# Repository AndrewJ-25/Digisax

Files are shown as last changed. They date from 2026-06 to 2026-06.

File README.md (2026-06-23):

# STARLITE

zine page

## Description
STARLITE is a minimalist Digital Saxophone (Digisax) controlled by ESP32-S3.

### Inspiration
This project is intended to be a cost effective, customisable alternative to commercially available wind synths. STARLITE can be used for both performance and silent practice. It weds my two favorite hobbies: music and tinkering.

### Features:
- realistic ergonomics
- UI in the form of an OLED display and rotary encoder, to control master volume and timbre
- differential pressure sensor for responsive breath control
- pressure tube and bleed tube to simulate realistic resistance to blowing
- audio synthesised locally
- 3x7 key matrix featuring MX Black switches
- power via 5V barrel jack
- DAC with headphone output

The neck can be blown into directly, but an alto saxophone mouthpiece is recommended. (Not included in this project.)

OnShape link: https://cad.onshape.com/documents/a64dba8dfd86a5efa1851173/w/8b62b2d00aa632cf961d9b4c/e/8ecfcb79b78c17c244b3f0aa

## Schematic and PCB

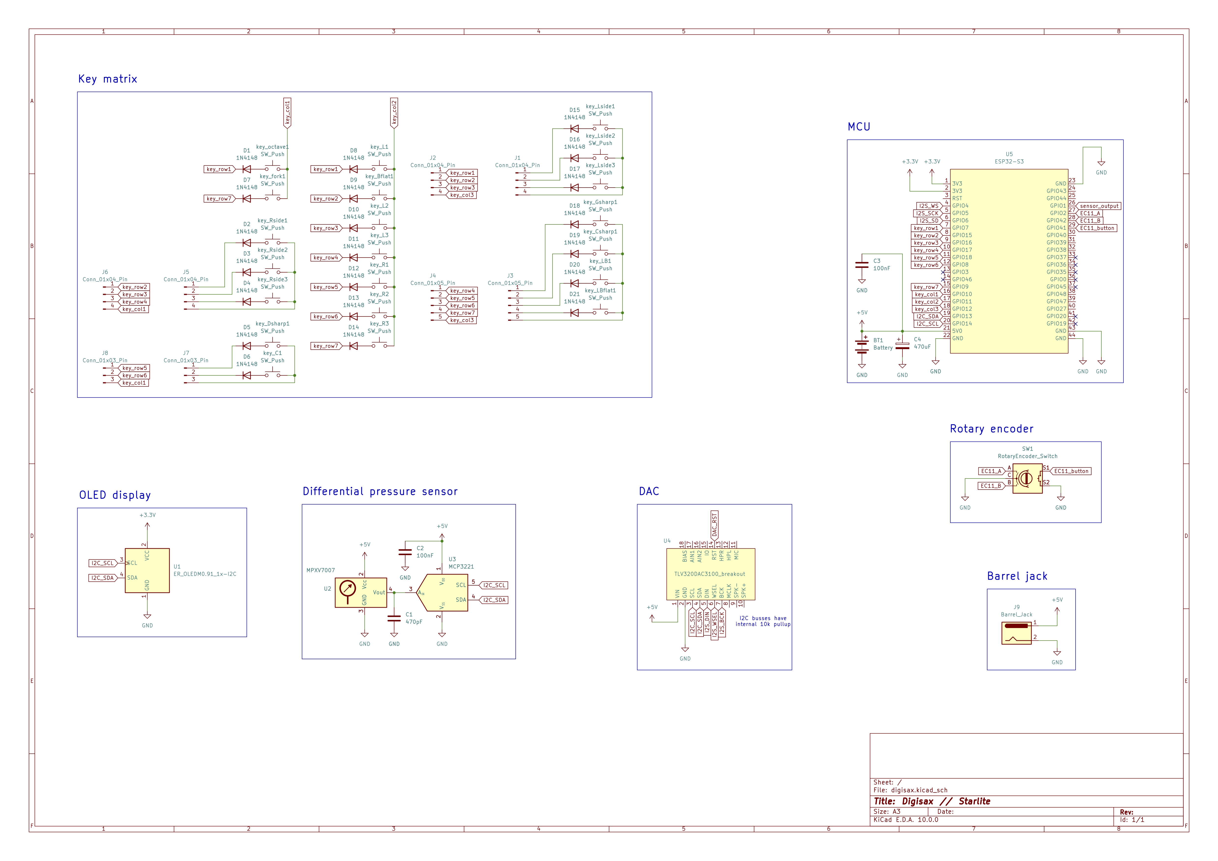
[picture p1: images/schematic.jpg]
Schematic view

A pdf version can be found under pcb/unconnected_pcb.

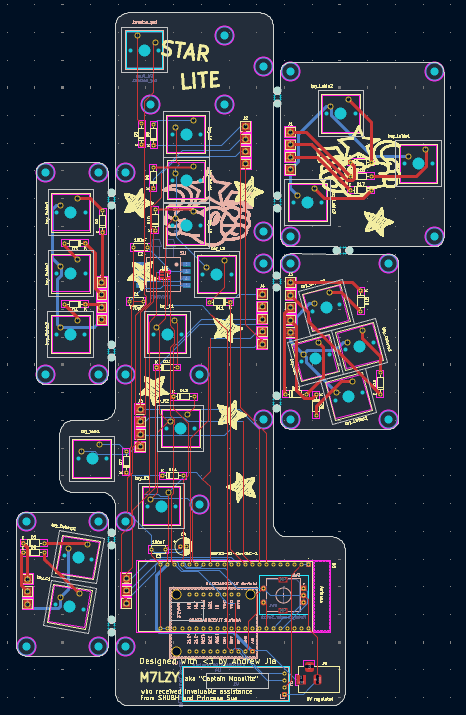
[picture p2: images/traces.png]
traces


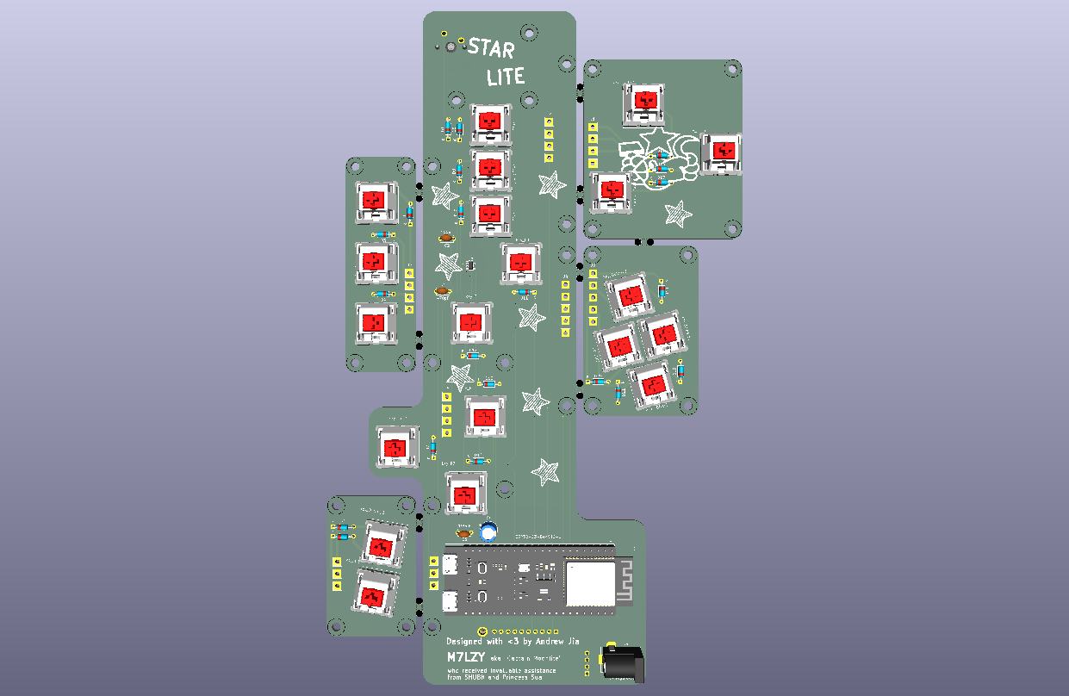
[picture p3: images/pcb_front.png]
pcb front

PCB front

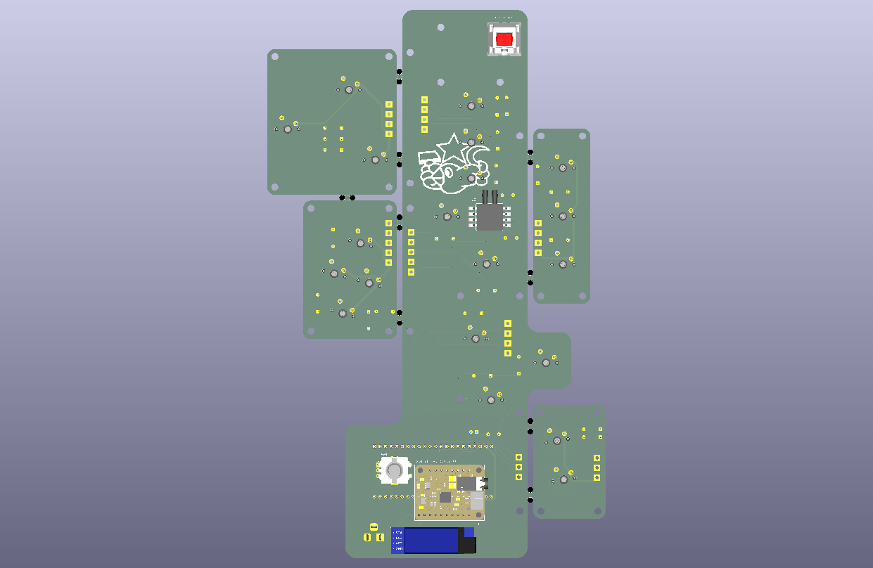
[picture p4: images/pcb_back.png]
pcb back

PCB back

NOTE: Kicad project contatining an unconnected, partially routed pcb can be found under pcb/unconnected_pcb. A fully routed, panelised pcb can be found under pcb/panelised_pcb. Gerber files were generated from the latter.

## Assembly
1. All parts can be handsoldered. I recommend soldering the key-switches last.
2. 3D printed parts to contain M3 heatset inserts.
3. Cut two lengths of food grade silicone tubing, 70mm (pressure tube) and 240mm (bleed tube) in length.
4. All plumbing is a push fit. Connect the pressure tube between the neck and pressure sensor. Bleed tube carries condensation from the neck to the bottom of the instrument. Holes in the right-hand-pinky-keys can hold the bleed tube in place.
5. All keycaps are a push fit. See images at bottom of page for correct placement.
6. Wrap cork around the neck to ensure an airtight fit with the mouthpiece.

3D printed parts:

|Quantity|Description|
|-|-|
|1|key B|
|1|key B-flat|
|1|key C-sharp|
|1|key G-sharp|
|3|key left palm|
|1|key low B flat|
|1|key Octave|
|3|key right palm|
|2|key right pinky|
|7|key round|
|1|mount left|
|1|mount left palm|
|1|mount left pinky|
|2|mount right palm|
|2|mount right pinky|

## BOM
|Quantity|Total cost/GBP|Description|MPN|Suggested source|
|-|-|-|-|-|
|1|16.88|PCB|-|https://jlcpcb.com/|
|1|6.30|DAC amplifier|Adafruit TLV320DAC3100 breakout board|https://thepihut.com/products/adafruit-tlv320dac3100-i2s-dac-with-headphone-and-speaker-out|
|1|10.40|MCU|ESP32-S3-DevKitC-1|https://www.aliexpress.com/item/1005009298826918.html|
|1|5.73|Differential pressure sensor|MPXV7007DP|https://www.aliexpress.com/item/1005009368234291.html|
|1|1.43|I2C ADC|MCP3221|https://www.mouser.co.uk/ProductDetail/Microchip-Technology/MCP3221A7T-E-OT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|
|21|23.49 (30pcs)|Keyboard switches|Cherry MX Black|https://www.ebay.co.uk/itm/203537430495?_skw=mx+black+switch|
|1|3.80|0.91" OLED display|SSD1306|https://www.aliexpress.com/item/1005006365845676.html|
|1|1.16|rotary encoder|EC11|https://www.aliexpress.com/item/1005005983134515.html|
|1|0.80|Barrel jack|DC-005|https://www.aliexpress.com/item/4001206395694.html|
|21|2.27|Diode|1N4148|https://www.aliexpress.com/item/1005010526571917.html|
|4|3.00|Capacitors|470pF, 100nF, 470uF|https://www.digikey.co.uk/|
|29|5.75 (50 pcs)|Screw M3|M3 * 12 Phillip's head|https://www.ebay.co.uk/itm/221326204336|
|29|8.88 (100 pcs)|Heat-set insert M3|M3 * 4 * 4.5|https://www.ebay.co.uk/itm/376068195160|
|1|3.20|Food grade silicone hose|ID 3mm OD 5mm length 1mm|https://www.ebay.co.uk/itm/227352704780?var=526554578797|
|1|5.44|cork sheet|~2mm thickness|https://www.ebay.co.uk/itm/277911247699|
|-|10|3D printed parts|-|-|
|TOTAL|108.53|-|-|-|

## Code

Firmware is written in C++.

Column pins use the ESP-32's internal pullup, and all row pins are set to high. I implemented a loop where all the rows are pulled high by default, and any column which is detected as low is matched with the key's corresponding row.

At the moment the code detects simultaneous key presses and prints the note which the current fingering corresponds to. Matrix and fingering mappings can be found in the code/ directory.

Note synthesis and volume control via the rotary encoder will be implemented once the project is built.

```cpp
#include <Arduino.h>
#include <map>
#include <initializer_list>

// =====================
// MATRIX PINS
// =====================

int Rows[] = {7, 15, 16, 17, 18, 8, 9};
int Columns[] = {10, 11, 12};

// =====================
// KEY NAMES
// =====================

const char* saxKey[7][3] =
{
    {"Octave1","L1","Ls1"},
    {"fork1","Bf1","Ls2"},
    {"Rs1","L2","Ls3"},
    {"Rs2","L3","Gsh1"},
    {"Rs3","R1","Csh1"},
    {"Dsh1","R2","LB1"},
    {"C1","R3","LBf1"}
};

// =====================
// BIT POSITIONS
// =====================

enum KeyBits
{
    OCTAVE1,
    L1,
    LS1,
    FORK1,
    BF1,
    LS2,
    RS1,
    L2,
    LS3,
    RS2,
    L3,
    GSH1,
    RS3,
    R1,
    CSH1,
    DSH1,
    R2,
    LB1,
    C1,
    R3,
    LBF1
};

// =====================
// KEY -> BIT LOOKUP
// =====================

std::map<String, uint8_t> keyToBit =
{
    {"Octave1", OCTAVE1},
    {"L1", L1},
    {"Ls1", LS1},
    {"fork1", FORK1},
    {"Bf1", BF1},
    {"Ls2", LS2},
    {"Rs1", RS1},
    {"L2", L2},
    {"Ls3", LS3},
    {"Rs2", RS2},
    {"L3", L3},
    {"Gsh1", GSH1},
    {"Rs3", RS3},
    {"R1", R1},
    {"Csh1", CSH1},
    {"Dsh1", DSH1},
    {"R2", R2},
    {"LB1", LB1},
    {"C1", C1},
    {"R3", R3},
    {"LBf1", LBF1}
};

// =====================
// FINGERING TABLE
// =====================

std::map<uint32_t, float> waves;

// =====================
// CREATE BITMASK
// =====================

uint32_t makeMask(std::initializer_list<uint8_t> keys)
{
    uint32_t mask = 0;

    for(auto key : keys)
    {
        mask |= (1UL << key);
    }

    return mask;
}

// =====================
// SETUP
// =====================

void setup()
{
    Serial.begin(115200);

    // Row pins output
    for(int i = 0; i < 7; i++)
    {
        pinMode(Rows[i], OUTPUT);
        digitalWrite(Rows[i], HIGH);
    }

    // Column pins input pullup
    for(int i = 0; i < 3; i++)
    {
        pinMode(Columns[i], INPUT_PULLUP);
    }

    // =====================
    // NOTE TABLE
    // =====================

    waves[makeMask({L1,L2,L3,R1,R2,R3,C1,LBF1})] = 138.59;
    waves[makeMask({L1,L2,L3,R1,R2,R3,C1,LB1})]  = 146.83;
    waves[makeMask({L1,L2,L3,R1,R2,R3,C1})]      = 155.56;
    waves[makeMask({L1,L2,L3,R1,R2,R3,C1,CSH1})] = 164.81;
    waves[makeMask({L1,L2,L3,R1,R2,R3})]         = 174.61;
    waves[makeMask({L1,L2,L3,R1,R2,R3,DSH1})]    = 185.00;
    waves[makeMask({L1,L2,L3,R1,R2})]            = 196.00;
    waves[makeMask({L1,L2,L3,R1})]               = 207.65;
    waves[makeMask({L1,L2,L3,R2})]               = 220.00;
    waves[makeMask({L1,L2,L3})]                  = 233.08;
    waves[makeMask({L1,L2,L3,GSH1})]             = 246.94;
    waves[makeMask({L1,L2})]                     = 261.63;
    waves[makeMask({L1,BF1})]                    = 277.18;
    waves[makeMask({L1})]                        = 293.66;
    waves[makeMask({L2})]                        = 311.13;
    waves[makeMask({})]                          = 329.63;

    Serial.println("Digital Sax Ready");
}

// =====================
// LOOP
// =====================

void loop()
{
    uint32_t currentMask = 0;

    // Scan all rows
    for(int row = 0; row < 7; row++)
    {
        // Disable all rows
        for(int r = 0; r < 7; r++)
        {
            digitalWrite(Rows[r], HIGH);
        }

        // Activate one row
        digitalWrite(Rows[row], LOW);

        delayMicroseconds(50);

        // Read columns
        for(int col = 0; col < 3; col++)
        {
            if(digitalRead(Columns[col]) == LOW)
            {
                const char* keyName = saxKey[row][col];

                currentMask |=
                    (1UL << keyToBit[String(keyName)]);

                Serial.print("Pressed: ");
                Serial.println(keyName);
            }
        }
    }

    // Lookup note
    auto note = waves.find(currentMask);

    if(note != waves.end())
    {
        Serial.print("Frequency: ");
        Serial.println(note->second);
    }
    else
    {
        Serial.println("Unknown fingering");
    }

    Serial.println("----------------");

    delay(50);
}
```

## More images

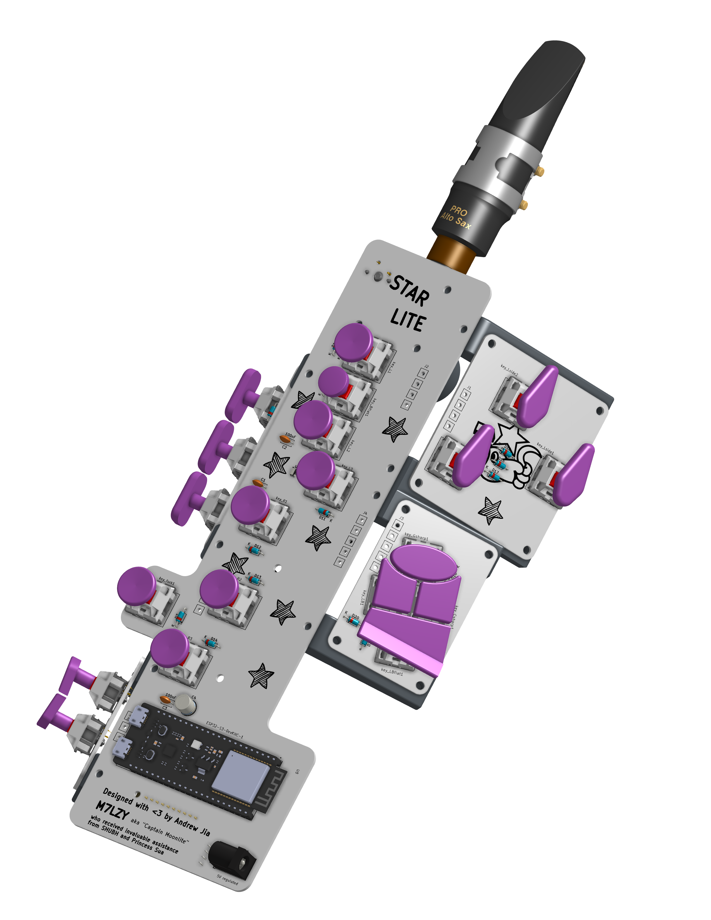
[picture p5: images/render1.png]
render


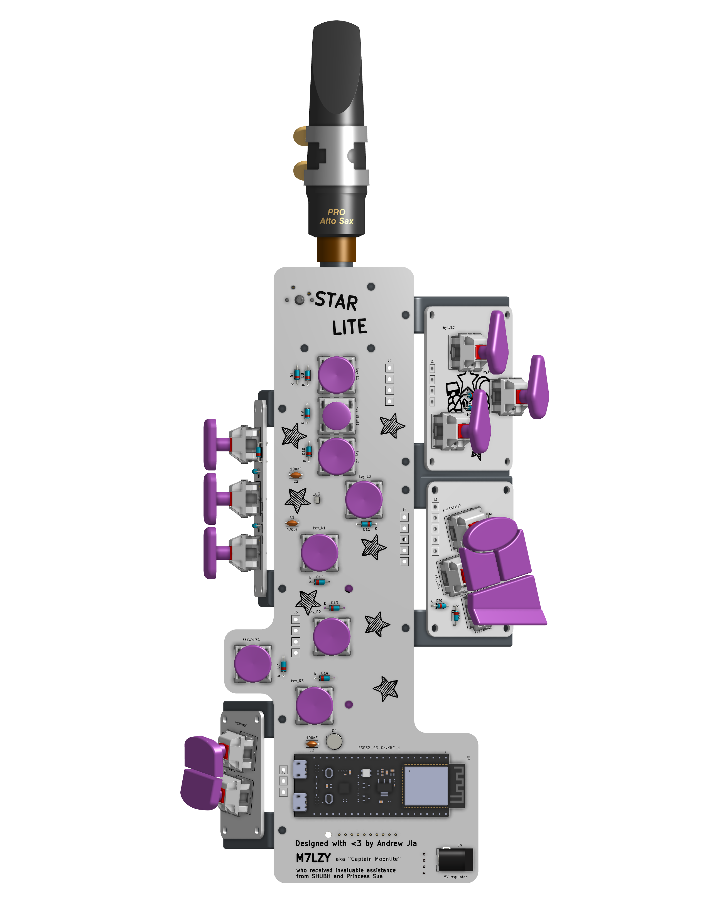
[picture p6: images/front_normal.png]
front view


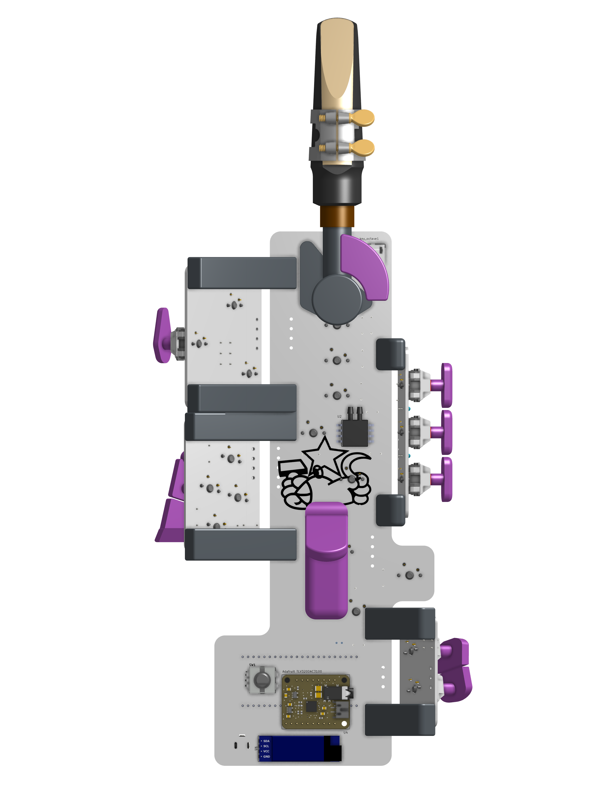
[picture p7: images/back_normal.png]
rear view


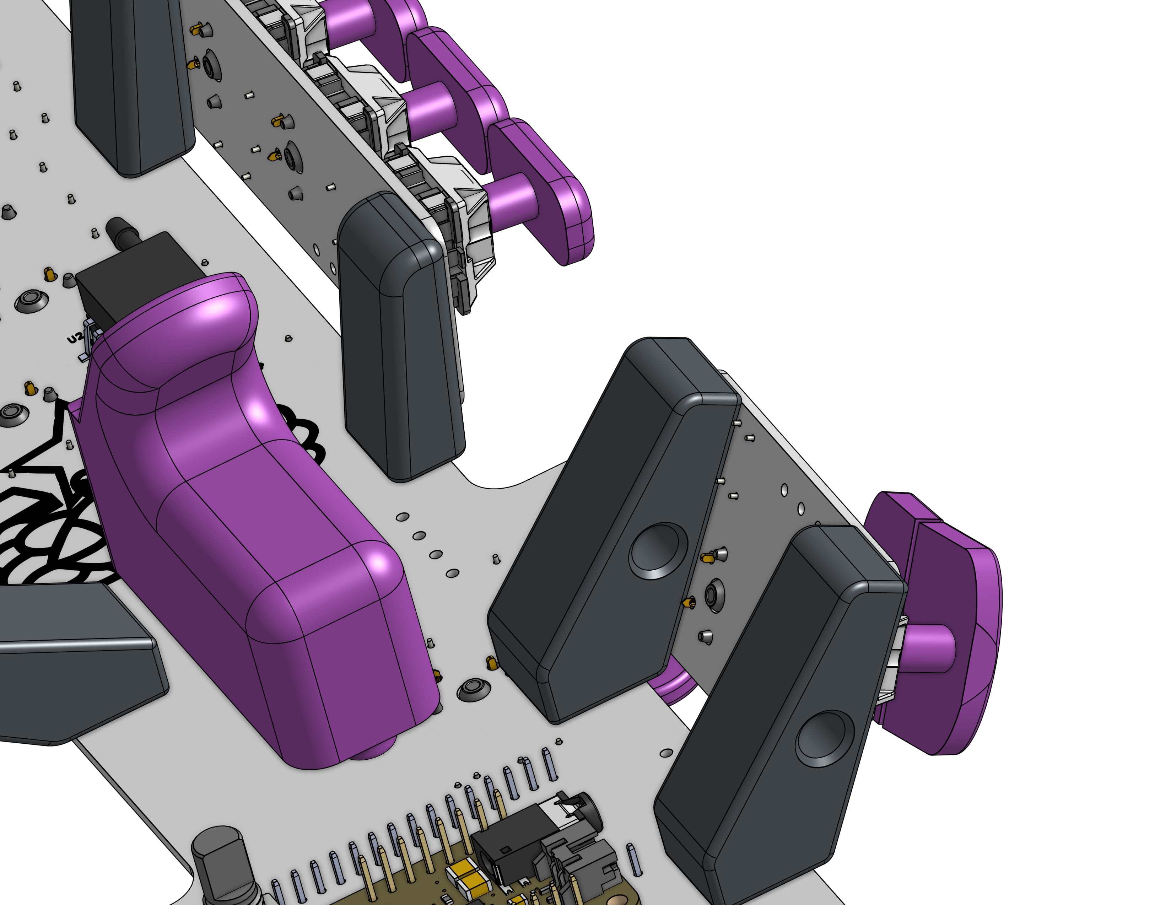
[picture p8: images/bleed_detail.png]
bleed tube mounting


## Acknowledgements <3

Massive thank you to Rehan for sacrificing his sleep to write the firmware.

Also to Sua for designing a BANGING zine.

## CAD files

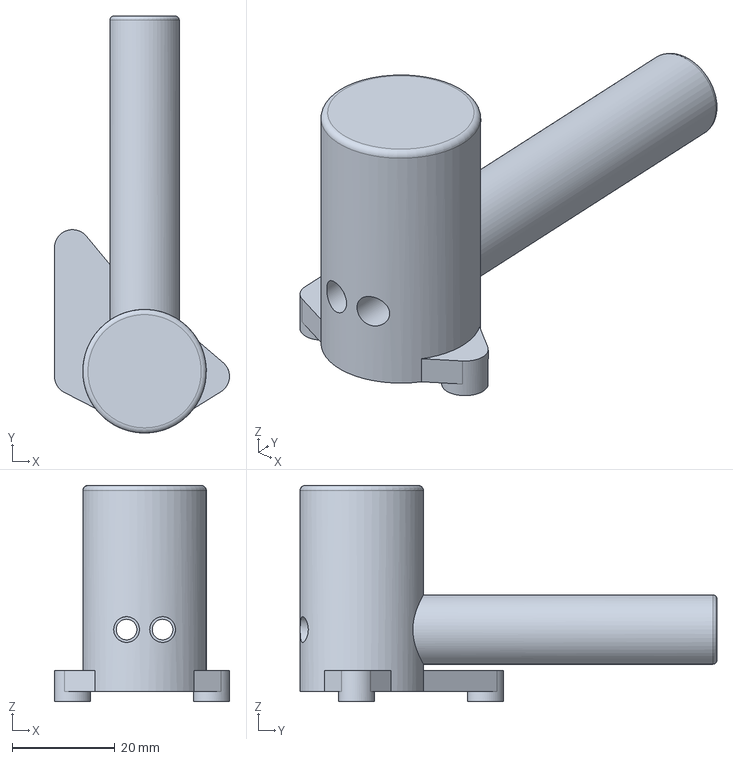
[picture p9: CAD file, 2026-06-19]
CAD/3D_printing/step/neck.step
34.0 x 81.0 x 42.0 mm

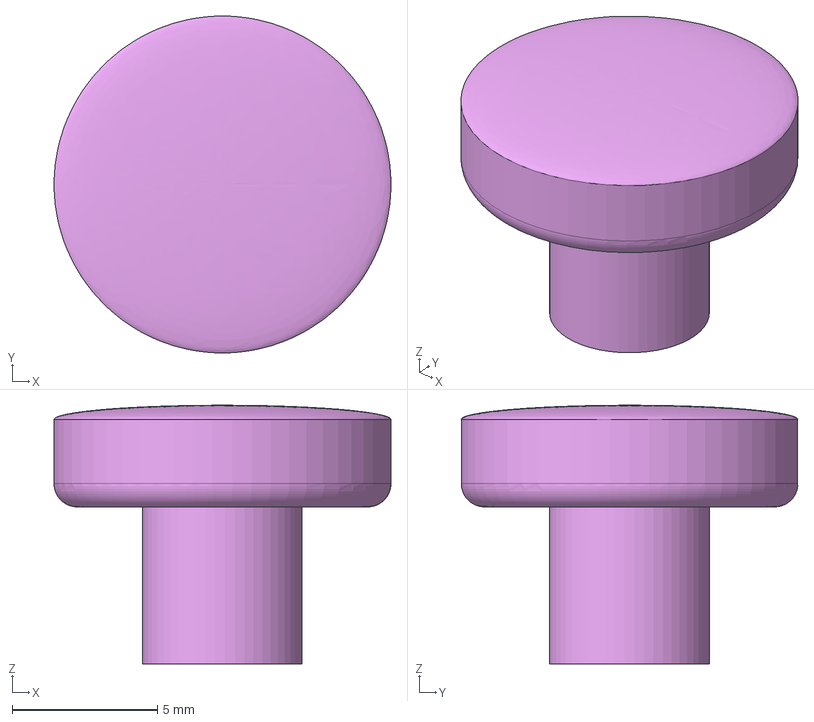
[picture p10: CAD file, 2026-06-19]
CAD/3D_printing/step/key_bflat.step
11.6 x 11.6 x 8.90 mm

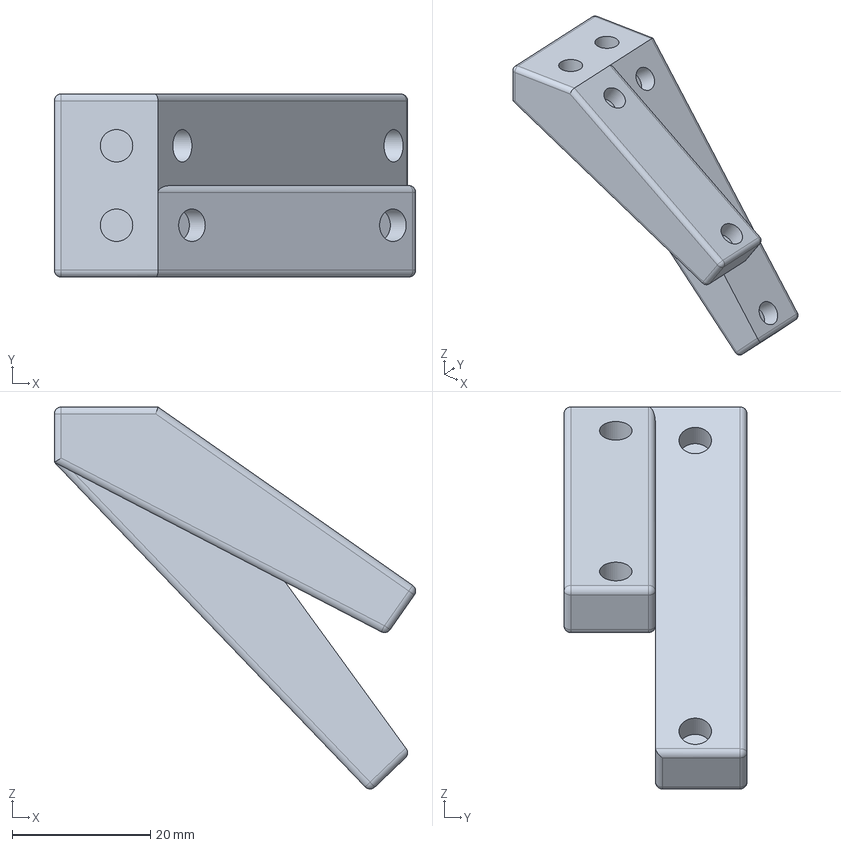
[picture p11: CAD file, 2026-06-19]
CAD/3D_printing/step/mount_left.step
52.3 x 26.5 x 55.3 mm

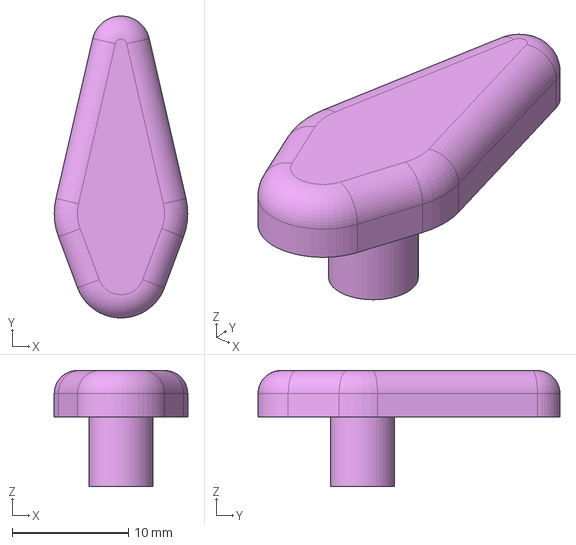
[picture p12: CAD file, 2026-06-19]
CAD/3D_printing/step/key_left_palm.step
11.5 x 26.0 x 10.0 mm

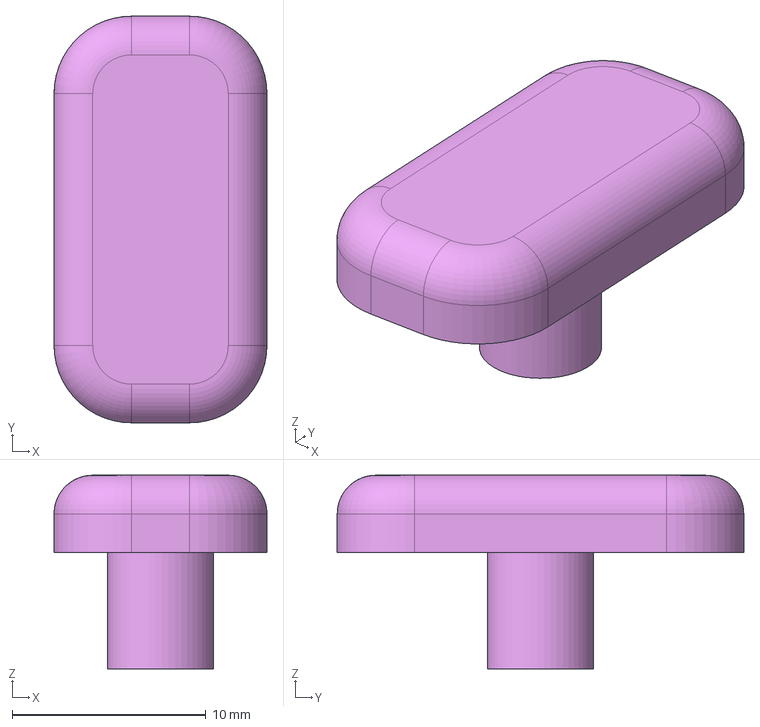
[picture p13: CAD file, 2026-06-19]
CAD/3D_printing/step/key_right_palm.step
11.0 x 21.0 x 10.0 mm

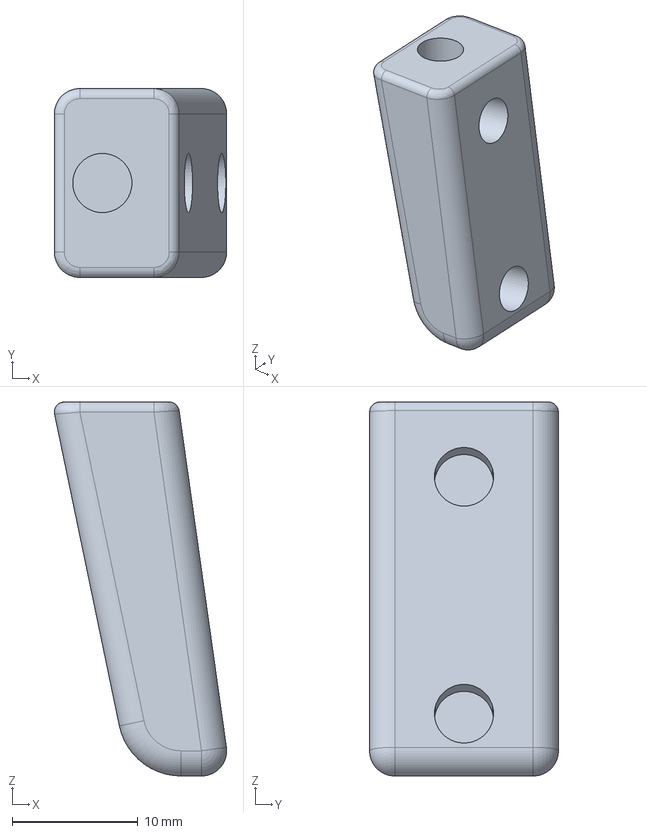
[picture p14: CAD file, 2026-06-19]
CAD/3D_printing/step/mount_right_palm.step
13.7 x 15.0 x 29.7 mm

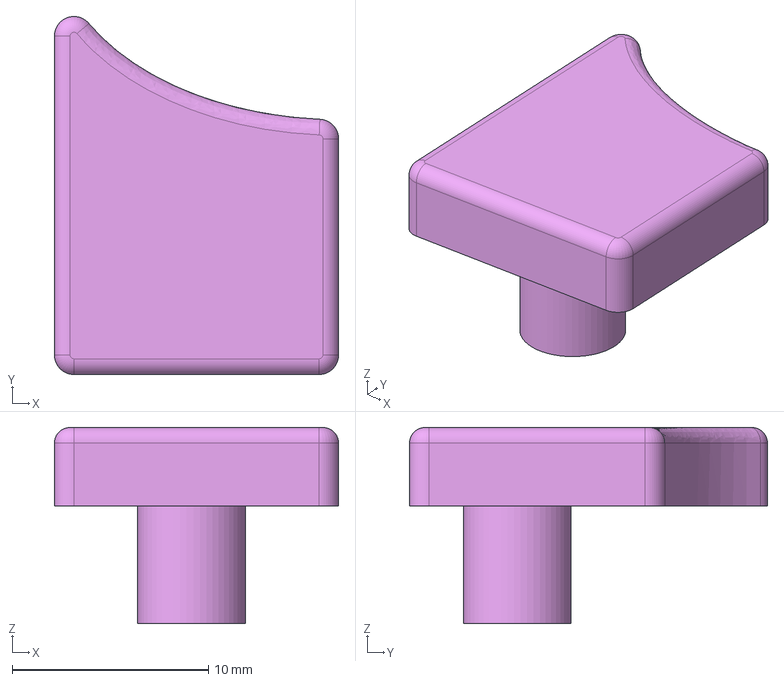
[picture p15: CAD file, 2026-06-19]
CAD/3D_printing/step/key_b.step
14.5 x 18.3 x 10.0 mm

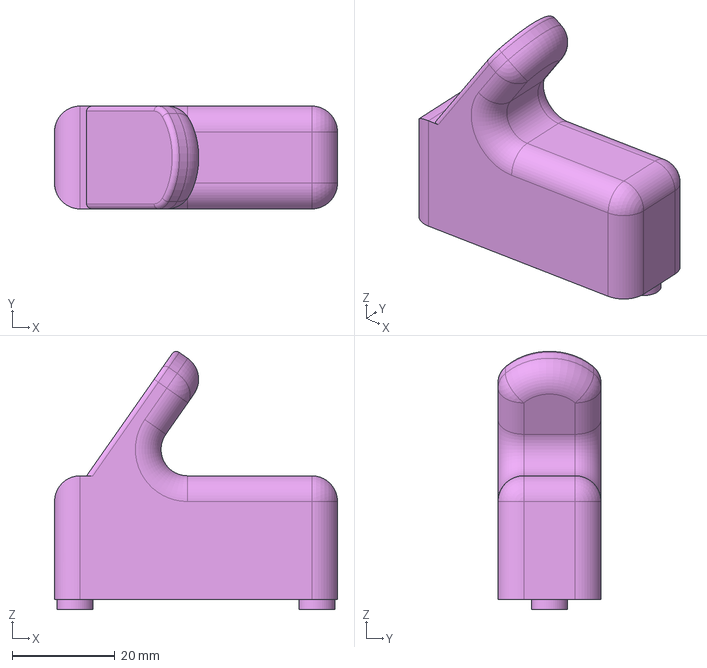
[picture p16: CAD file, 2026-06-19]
CAD/3D_printing/step/thumb_rest.step
55.0 x 20.0 x 50.2 mm

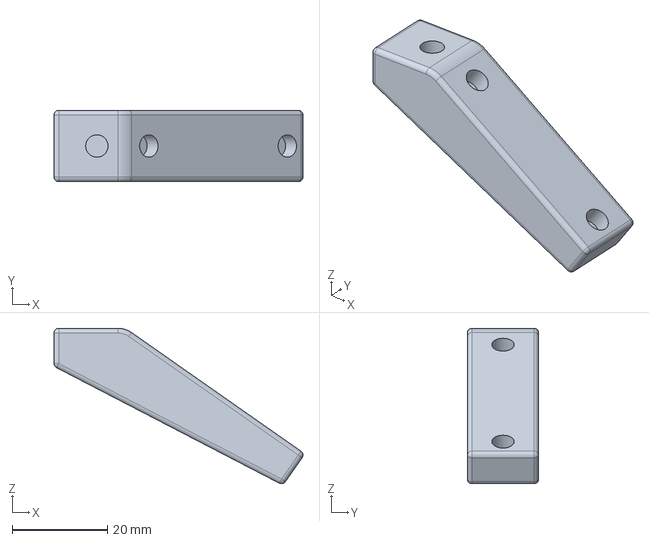
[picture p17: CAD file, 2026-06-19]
CAD/3D_printing/step/mount_left_pinky.step
52.3 x 15.0 x 32.6 mm

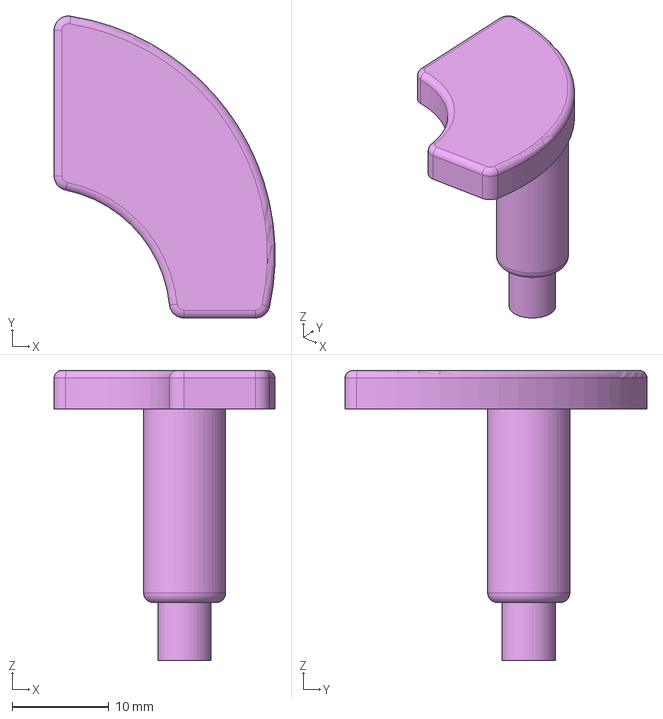
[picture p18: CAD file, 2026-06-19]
CAD/3D_printing/step/key_octave.step
22.8 x 31.2 x 30.0 mm

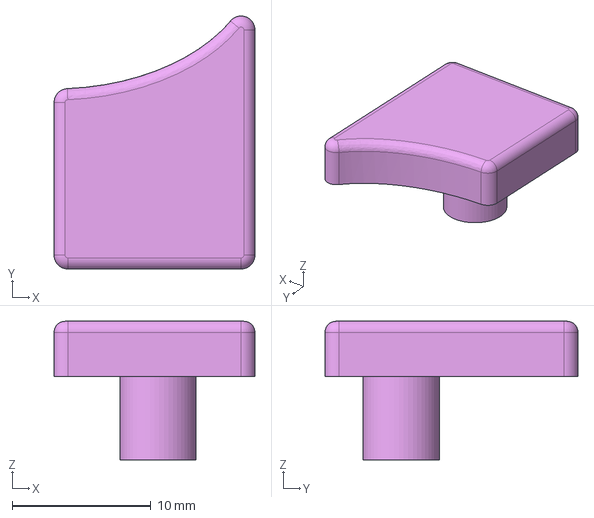
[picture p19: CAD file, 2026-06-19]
CAD/3D_printing/step/key_csharp.step
14.5 x 18.3 x 10.0 mm

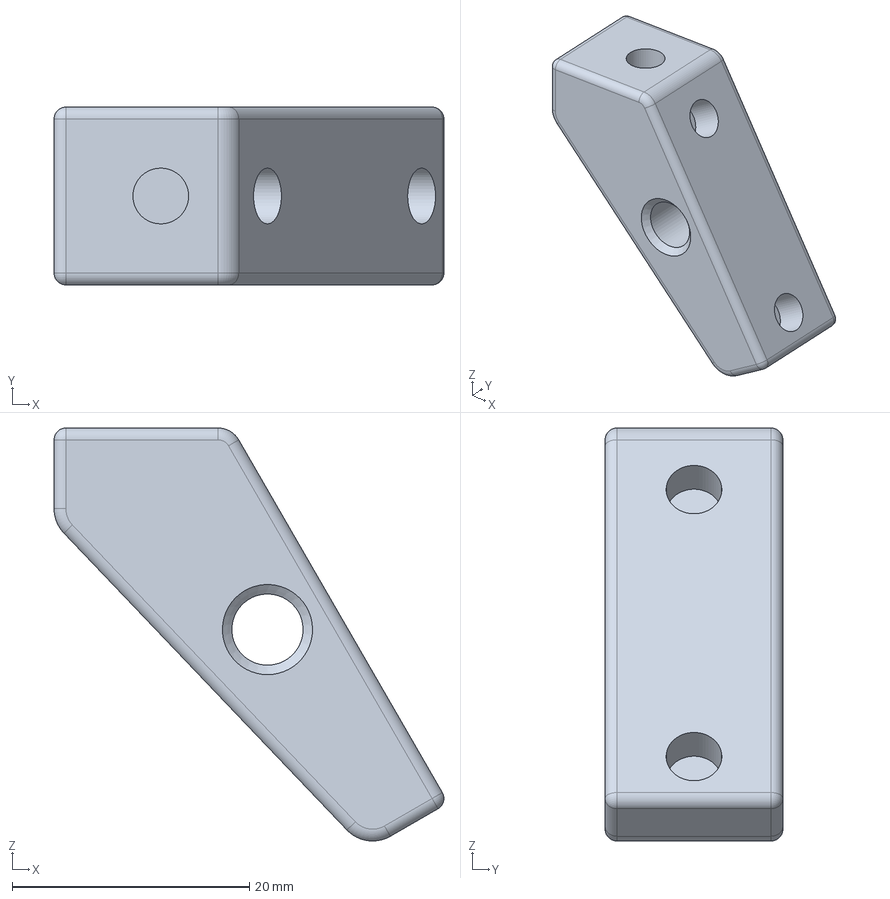
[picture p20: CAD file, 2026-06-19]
CAD/3D_printing/step/mount_right_pinky.step
32.9 x 15.0 x 34.8 mm

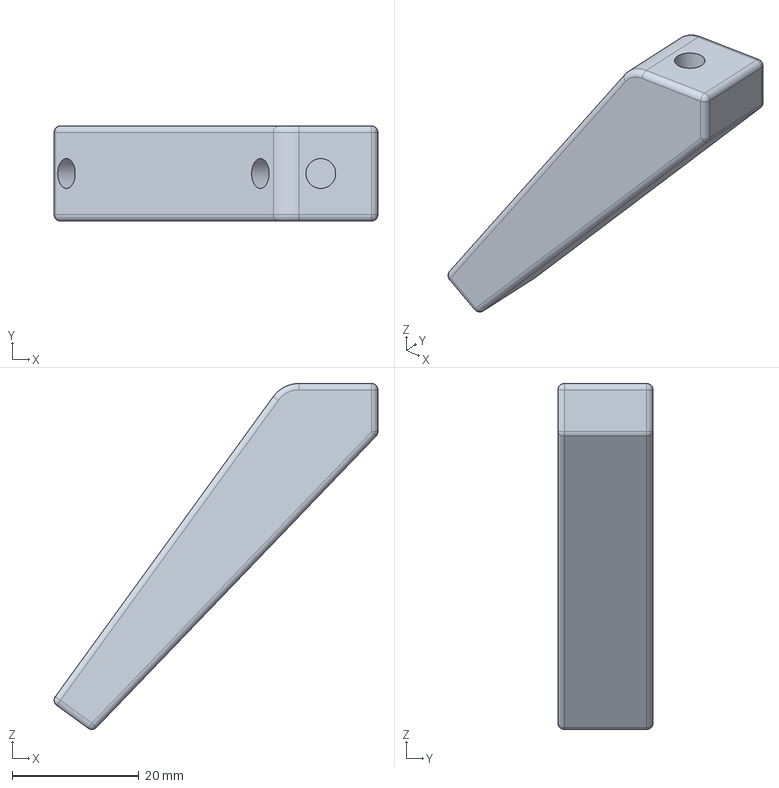
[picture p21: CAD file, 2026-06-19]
CAD/3D_printing/step/mount_left_palm.step
51.0 x 15.0 x 54.5 mm

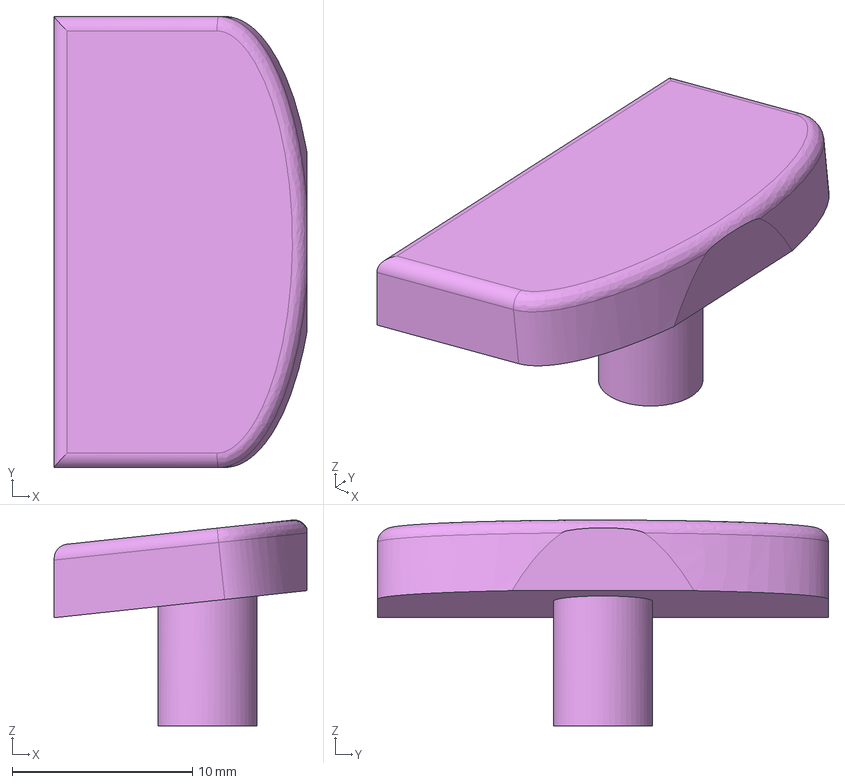
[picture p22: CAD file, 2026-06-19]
CAD/3D_printing/step/key_right_pinky.step
14.0 x 25.0 x 11.4 mm

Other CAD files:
CAD/3D_printing/step/key_low_bflat.step
CAD/3D_printing/step/key_gsharp.step
CAD/3D_printing/step/key_round.step
CAD/3D_printing/stl/key_b.stl
CAD/3D_printing/stl/key_bflat.stl
CAD/3D_printing/stl/key_csharp.stl
CAD/3D_printing/stl/key_gsharp.stl
CAD/3D_printing/stl/key_left_palm.stl
CAD/3D_printing/stl/key_low_bflat.stl
CAD/3D_printing/stl/key_octave.stl
CAD/3D_printing/stl/key_right_palm.stl
CAD/3D_printing/stl/key_right_pinky.stl
CAD/3D_printing/stl/key_round.stl
CAD/3D_printing/stl/mount_left.stl
CAD/3D_printing/stl/mount_left_palm.stl
CAD/3D_printing/stl/mount_left_pinky.stl
CAD/3D_printing/stl/mount_right_palm.stl
CAD/3D_printing/stl/mount_right_pinky.stl
CAD/3D_printing/stl/neck.stl
CAD/3D_printing/stl/thumb_rest.stl

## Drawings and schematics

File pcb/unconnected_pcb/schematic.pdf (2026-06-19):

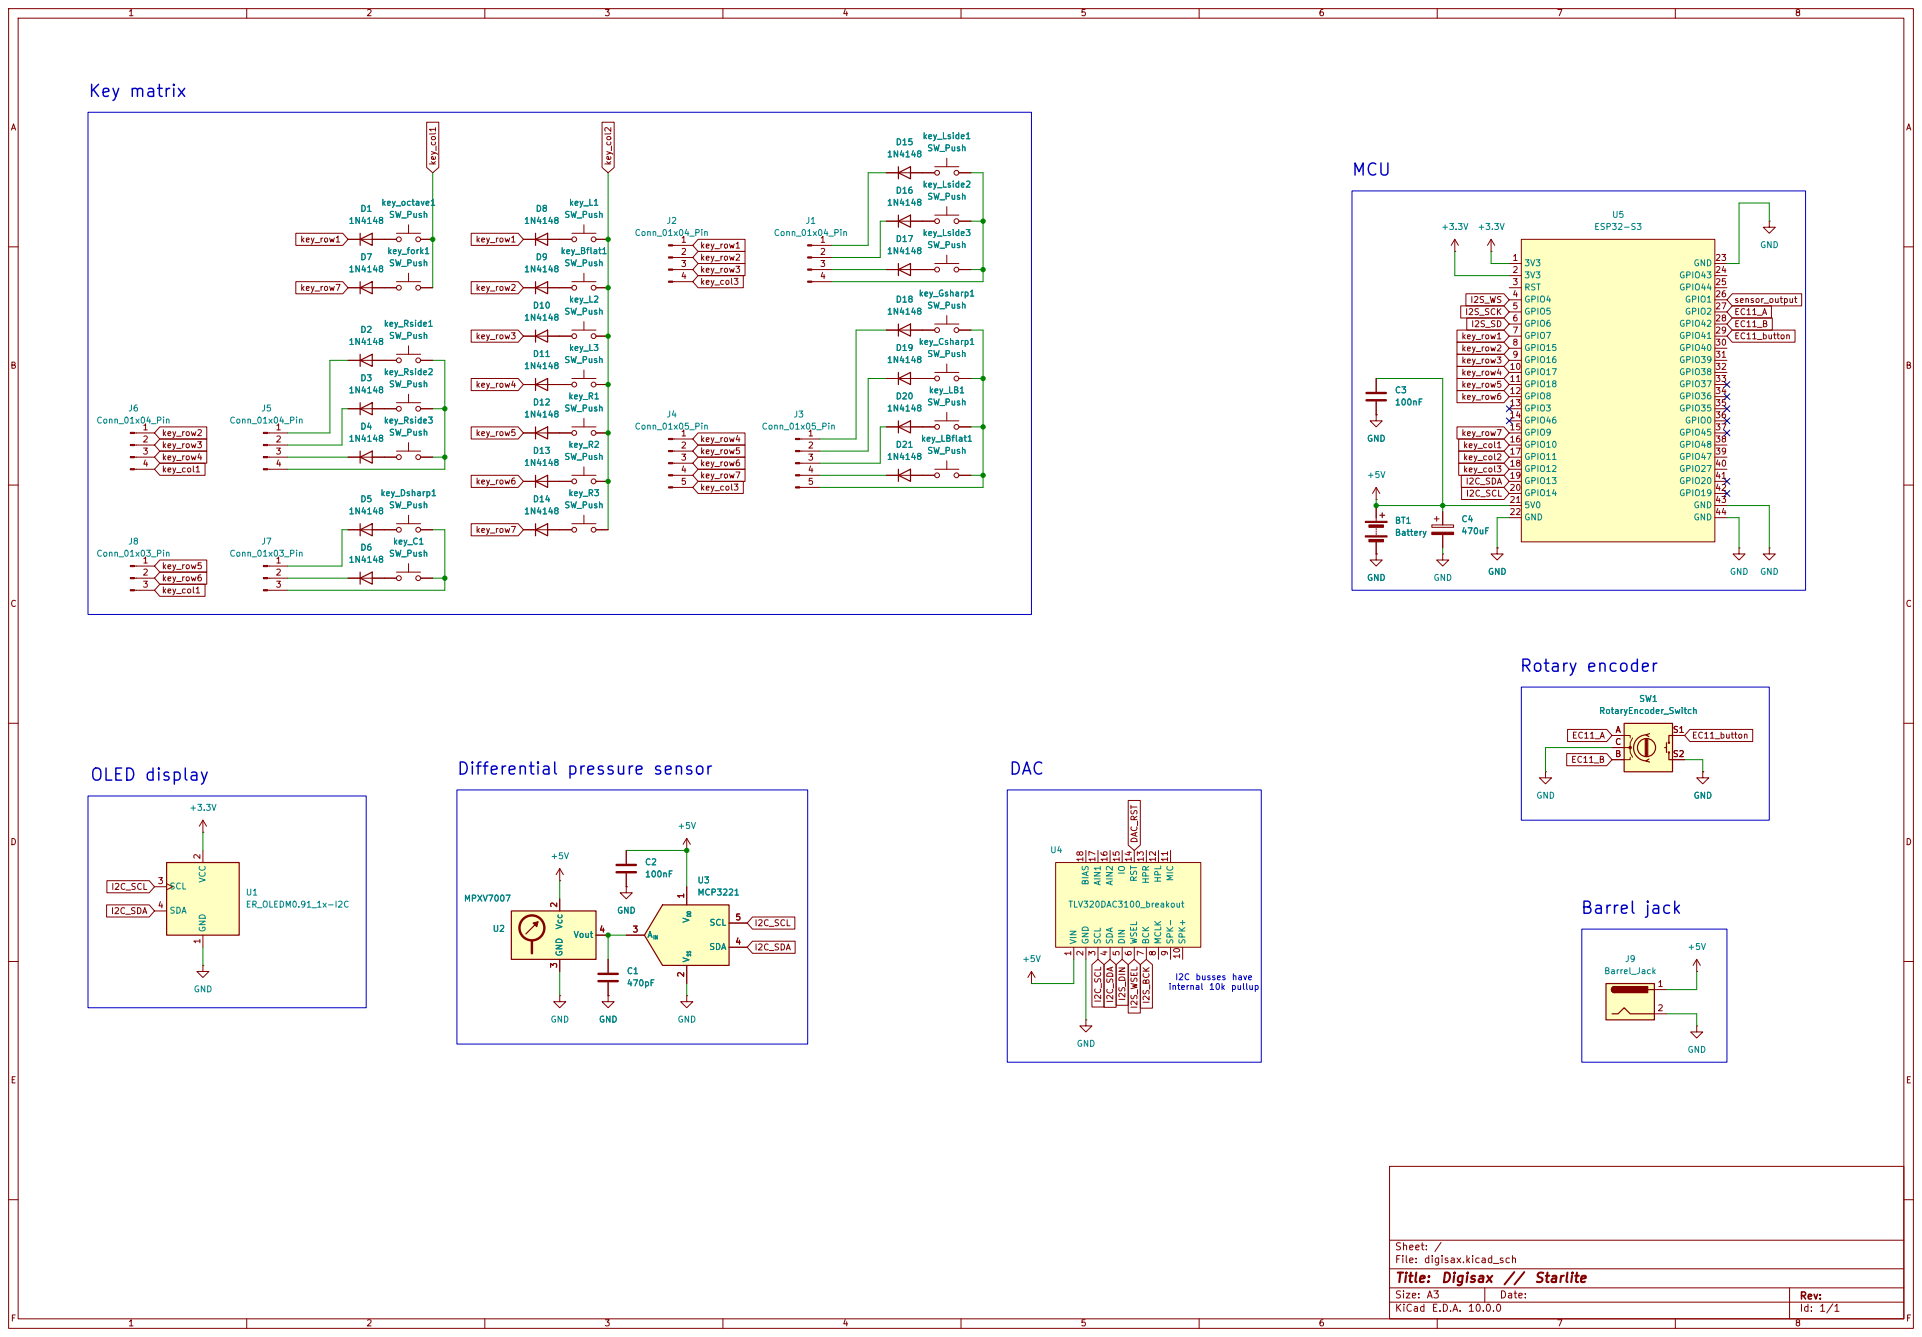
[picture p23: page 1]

9 SPK+ 10 MIC 11 HPL 12 HPR 13 RST 14 IO 15 AIN2 16 AIN1 17 BIAS 18U4

Size: A3 | Rev: | F Date:
KiCad E.D.A. 10.0.0 | Id: 1/1

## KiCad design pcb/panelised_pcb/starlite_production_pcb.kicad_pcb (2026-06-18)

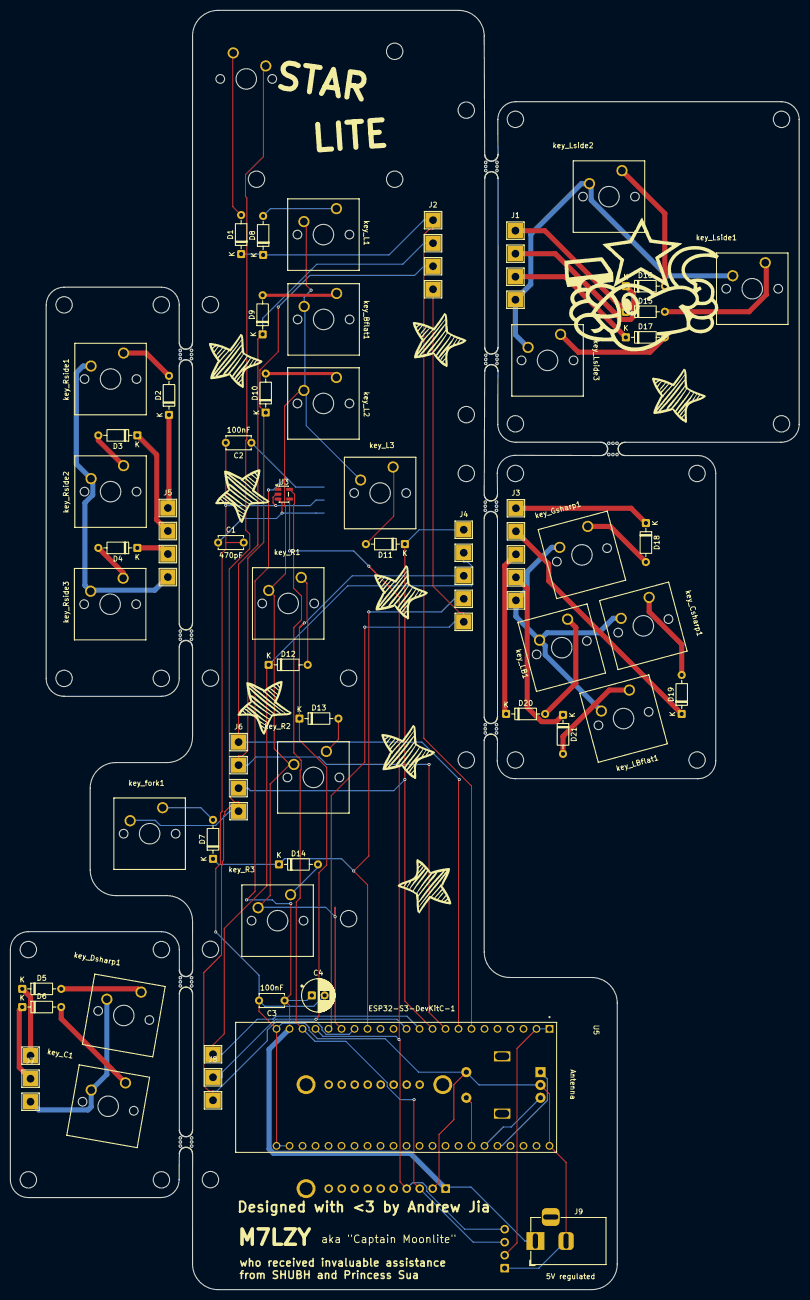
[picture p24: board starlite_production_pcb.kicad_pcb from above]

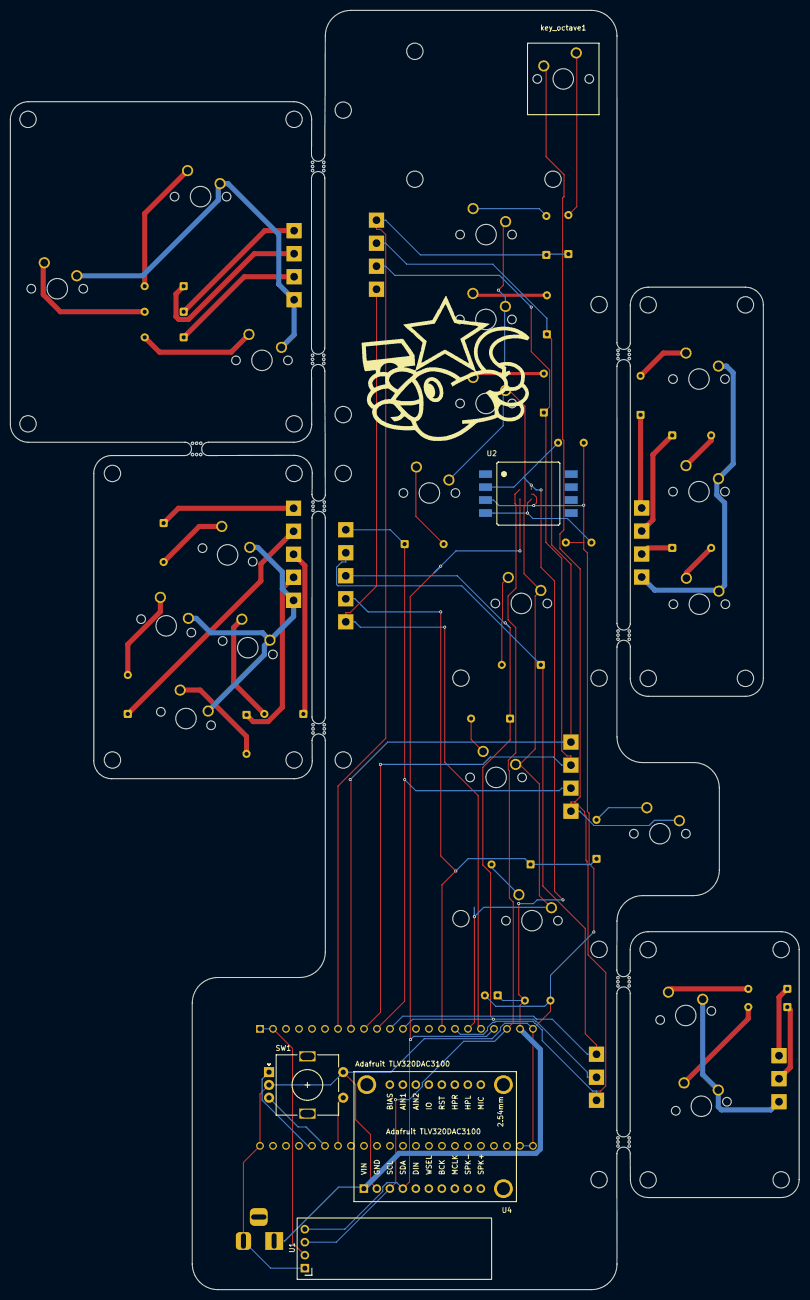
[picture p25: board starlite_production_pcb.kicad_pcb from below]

Board: 2 copper layers, 154.2 x 250.0 mm, 99 parts (5 on the bottom side), 56 nets.

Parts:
C1: 470pF; C_Disc_D4.7mm_W2.5mm_P5.00mm
C2, C3: 100nF; C_Disc_D4.7mm_W2.5mm_P5.00mm
C4: 470uF; CP_Radial_D6.3mm_P2.50mm
D1, D2, D3, D4, D5, D6, D7, D8, D9, D10, D11, D12, D13, D14, D15, D16, D17, D18, D19, D20, D21: 1N4148; D_DO-35_SOD27_P7.62mm_Horizontal
J1, J2, J5, J6: Conn_01x04_Pin; pad_1x4
J3, J4: Conn_01x05_Pin; pad_1x5
J7, J8: Conn_01x03_Pin; pad_1x3
J9: Barrel_Jack; BarrelJack_Horizontal
SW1: RotaryEncoder_Switch; RotaryEncoder_Alps_EC11E-Switch_Vertical_H20mm
U1: ER_OLEDM0.91_1x-I2C
U2: MPXV7007; MPXV7007DP
U3: MCP3221; SOT-23-5
U4: TLV320DAC3100_breakout; adafruit_TLV320DAC3100
U5: ESP32-S3; ESP32-S3-DevKitC-1
h1, h2, h3, h4, h5, h6, h7, h8, h9, h10, h11, h12, h13, h14, h16, h17, h18, h19, h20, h21, h22, h23, h24, h25: MountingHole_3.2mm_M3
key_Bflat1: SW_Push; slim_switch
key_C1: SW_Push; slim_switch
key_Csharp1: SW_Push; slim_switch
key_Dsharp1: SW_Push; slim_switch
key_Gsharp1: SW_Push; slim_switch
key_L1, key_L2, key_L3: SW_Push; slim_switch
key_LB1: SW_Push; slim_switch
key_LBflat1: SW_Push; slim_switch
key_Lside1, key_Lside2, key_Lside3: SW_Push; slim_switch
key_R1, key_R2, key_R3: SW_Push; slim_switch
key_Rside1, key_Rside2, key_Rside3: SW_Push; slim_switch
key_fork1: SW_Push; slim_switch
key_octave1: SW_Push; slim_switch
mouse-bite-2.54mm-slot, mouse-bite-2.54mm-slot#2, mouse-bite-2.54mm-slot#3, mouse-bite-2.54mm-slot#4, mouse-bite-2.54mm-slot#5, mouse-bite-2.54mm-slot#6, mouse-bite-2.54mm-slot#7, mouse-bite-2.54mm-slot#8, mouse-bite-2.54mm-slot#9: VAL**; mouse-bite-2.54mm-slot
neck1, neck2, neck3: MountingHole_3.2mm_M3
thumb1, thumb2: MountingHole_3.2mm_M3

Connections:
+3.3V: U1.2 (VCC), U5.1 (3V3), U5.2 (3V3)
+5V: C2.1, C3.1, C4.1, J9.1, U2.2 (Vcc), U3.1 (V_{DD}), U4.1 (VIN), U5.21 (5V0)
EC11_A: SW1.A, U5.27 (GPIO2)
EC11_B: SW1.B, U5.28 (GPIO42)
EC11_button: SW1.S1, U5.29 (GPIO41)
GND: C1.2, C2.2, C3.2, C4.2, J9.2, SW1.C, SW1.S2, U1.1 (GND), U2.3 (GND), U3.2 (V_{SS}), U4.2 (GND), U5.22 (GND), U5.23 (GND), U5.43 (GND), U5.44 (GND)
I2C_SCL: U1.3 (SCL), U3.5 (SCL), U4.3 (SCL), U5.20 (GPIO14)
I2C_SDA: U1.4 (SDA), U3.4 (SDA), U4.4 (SDA), U5.19 (GPIO13)
unnamed: D1.2 (A), key_octave1.1
unnamed: D2.2 (A), key_Rside1.1
unnamed: D2.1 (K), J5.1
unnamed: D3.2 (A), key_Rside2.1
unnamed: D3.1 (K), J5.2
unnamed: D4.2 (A), key_Rside3.1
unnamed: D4.1 (K), J5.3
unnamed: D5.2 (A), key_Dsharp1.1
unnamed: D5.1 (K), J7.1
unnamed: D6.2 (A), key_C1.1
unnamed: D6.1 (K), J7.2
unnamed: D7.2 (A), key_fork1.1
unnamed: D8.2 (A), key_L1.1
unnamed: D9.2 (A), key_Bflat1.1
unnamed: D10.2 (A), key_L2.1
unnamed: D11.2 (A), key_L3.1
unnamed: D12.2 (A), key_R1.1
unnamed: D13.2 (A), key_R2.1
unnamed: D14.2 (A), key_R3.1
unnamed: D15.2 (A), key_Lside1.1
unnamed: D15.1 (K), J1.1
unnamed: D16.2 (A), key_Lside2.1
unnamed: D16.1 (K), J1.2
unnamed: D17.2 (A), key_Lside3.1
unnamed: D17.1 (K), J1.3
unnamed: D18.2 (A), key_Gsharp1.1
unnamed: D18.1 (K), J3.1
unnamed: D19.2 (A), key_Csharp1.1
unnamed: D19.1 (K), J3.2
unnamed: D20.2 (A), key_LB1.1
unnamed: D20.1 (K), J3.3
unnamed: D21.2 (A), key_LBflat1.1
unnamed: D21.1 (K), J3.4
unnamed: J1.4, key_Lside1.2, key_Lside2.2, key_Lside3.2
unnamed: J3.5, key_Csharp1.2, key_Gsharp1.2, key_LB1.2, key_LBflat1.2
unnamed: J5.4, key_Rside1.2, key_Rside2.2, key_Rside3.2
unnamed: J7.3, key_C1.2, key_Dsharp1.2
unnamed: C1.1, U2.4 (Vout), U3.3 (A_{IN})
key_col1: J6.4, J8.3, U5.16 (GPIO10), key_fork1.2, key_octave1.2
key_col2: U5.17 (GPIO11), key_Bflat1.2, key_L1.2, key_L2.2, key_L3.2, key_R1.2, key_R2.2, key_R3.2
key_col3: J2.4, J4.5, U5.18 (GPIO12)
key_row1: D1.1 (K), D8.1 (K), J2.1, U5.7 (GPIO7)
key_row2: D9.1 (K), J2.2, J6.1, U5.8 (GPIO15)
key_row3: D10.1 (K), J2.3, J6.2, U5.9 (GPIO16)
key_row4: D11.1 (K), J4.1, J6.3, U5.10 (GPIO17)
key_row5: D12.1 (K), J4.2, J8.1, U5.11 (GPIO18)
key_row6: D13.1 (K), J4.3, J8.2, U5.12 (GPIO8)
key_row7: D7.1 (K), D14.1 (K), J4.4, U5.15 (GPIO9)

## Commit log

2026-05-16 symbols and shi
    [digisax.kicad_pcb, digisax.kicad_sch]
2026-05-21 completed esp32 devboard symbol
    [digisax.kicad_sch]
2026-05-24 drew symbols for dac and manometer
    [digisax.kicad_sch]
2026-05-24 tidied up a bit
    [digisax.kicad_sch]
2026-06-01 started to added switches for keys
    [digisax.kicad_sch]
2026-06-02 added all switches, update symbols
    [digisax.kicad_sch]
2026-06-03 added adc to schematic
    [digisax.kicad_sch]
2026-06-06 added new dac to schem
    [digisax.kicad_sch]
2026-06-06 started matrix wiring
    [digisax.kicad_sch]
2026-06-08 completed first iteration of schem
    [digisax.kicad_sch]
2026-06-08 added decoupling caps
    [digisax.kicad_sch]
2026-06-09 custom dac footprint
2026-06-13 completed footprints and 3d models
    [digisax.kicad_pcb, digisax.kicad_sch]
2026-06-13 added all symbols :D
    [digisax.kicad_pcb, digisax.kicad_sch]
2026-06-13 new switch models.. yeah
    [digisax.kicad_pcb, digisax.kicad_sch]
2026-06-13 switch placement according to irl sax
    [digisax.kicad_pcb, digisax.kicad_sch]
2026-06-14 added headers to schem
    [digisax.kicad_pcb, digisax.kicad_sch]
2026-06-14 more kcal burnt on pcb
    [digisax.kicad_pcb, digisax.kicad_sch]
2026-06-15 added schematic pdf
2026-06-15 fixed schematic labels
    [digisax.kicad_sch]
2026-06-15 updated schematic pdf
2026-06-15 created fingering chart
2026-06-15 added barrel jack, sketched board outline
    [digisax.kicad_pcb, digisax.kicad_sch]
2026-06-15 had a go at routing
    [digisax.kicad_pcb, digisax.kicad_sch]
2026-06-15 routed central board in new kicad project
    [central_board.kicad_pcb, central_board.kicad_sch, digisax.kicad_pcb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]
2026-06-16 Enhance README with code example and BOM
    Added code example for matrix scanning with ESP-32 and updated README with BOM details.
2026-06-16 added silkscreen art
    [digisax.kicad_pcb]
2026-06-16 routed central board
    [digisax.kicad_pcb]
2026-06-16 Ignore history directory
    [central_board.kicad_pcb, digisax.kicad_pcb, starlite_production_pcb.kicad_pcb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]
2026-06-16 exported pcb step
    [starlite_production_pcb.kicad_pcb]
2026-06-17 rearranged to fix clearance and alignment
    [digisax.kicad_pcb]
2026-06-17 routed new pcb
    [starlite_production_pcb.kicad_pcb]
2026-06-17 the birds the word/ removed the bird
    [digisax.kicad_pcb]
2026-06-17 added the bird
    [starlite_production_pcb.kicad_pcb]
2026-06-18 added mouse bites to startlite_production_pcb
    [digisax.kicad_sch, freerouting.dsn, starlite_production_pcb.kicad_pcb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]
2026-06-19 pcb render
2026-06-19 added gerbers
2026-06-19 exported step files
    [key_b.step, key_bflat.step, key_csharp.step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]
2026-06-19 modified neck
    [neck.step]
2026-06-19 vell this is awkward
    [digisax.kicad_sch]
2026-06-19 exported schematic as png
2026-06-19 exported stl
    [key_b.stl, key_bflat.stl, key_csharp.stl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]
2026-06-19 created bom
2026-06-23 screenshot pcb
2026-06-23 added CAD folder, exported schematic png from pdf
    [key_b.step, key_b.stl, key_bflat.step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]
2026-06-23 moved schematic png
2026-06-23 exported better schematic png
2026-06-23 moved kicad files
    [digisax.kicad_pcb, digisax.kicad_sch, starlite_production_pcb.kicad_pcb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]
